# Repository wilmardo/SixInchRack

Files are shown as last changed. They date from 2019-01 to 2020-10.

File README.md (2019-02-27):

# SixInchRack

This is a project for 6" cabinets and rack enclusures.

For pictures have a look here:
 - http://www.thingiverse.com/thing:1957436
 - http://www.thingiverse.com/thing:1936196
 - http://www.thingiverse.com/thing:2084736

The project is a scaled down version of the familiar 19" rack standard, with the following size:
 - 1U is 14mm
 - The front plate is 155mm wide
 - The inside distance between the two vertical profiles is 115mm
 - The ears protrude 20mm

It is designed for the 20x20 extruded aluminium profile, but a profile can also be printed.

Screws:
 - M4x6 for the nutless trap
 - M6x16 for the top and bottom
 - M3x12 for the cabinet

##I want to print a simple blank six inch cabinet
Go Thingiverse and locate this build: http://www.thingiverse.com/thing:1957436
In the customizer you specify how many units you need in height, and depth in mm you need.
Alternatively, fetch these files from the repository:...

##I want to print a simple six inch rack enclosure for cabinets
Go Thingiverse and locate this build: http://www.thingiverse.com/thing:1957436
In the customizer you specify which parts you need.
Alternatively, fetch these files from the repository:...

##I want to print a 6" cabinet for a specific component
Either go to thingiverse where you can find the stl's and pictures, or download the stl's form this repository. Currently the following components are supported by the community:

- http://www.thingiverse.com/thing:2084736 Raspberry Pi 3 Model B
- http://www.thingiverse.com/thing:1905998 Raspberry Pi B
- http://www.thingiverse.com/thing:2151578 Beaglebone Black
- http://www.thingiverse.com/thing:2123108 DPS5005 power supply
- http://www.thingiverse.com/thing:2105698 Beaglebone Black

##I want to make a new cabinet for my favourite module
Start by inspecting this file for inspiration _RackCabinets/RaspberryPiModelB/usb_back.scad_, and take a look at the how to section below.

1. Create a new file that includes _sixinch_library.scad_
2. Customize all the parts needed for your cabinet
3. Create a new folder with you project, and anything else needed like print descriptions
4. If you like, create a Thingiverse build with pictures and your stl, and add a link in this file

##Quick How To##
A cabinet consist of five parts:
- Front plate
- Back plate
- Cabinet
- Lid
- Handles

In a new file, include _sixinch_library.scad_. For each of the parts, there is module in the library where you can specify the most commonly used features like round and square holes, and pegs for supporting PCB's etc. The following examples are for Raspberry Pi 3 cabinet. <br>
The deafult modules obviously does not support everything you need, but should give you a good start for further customization. Feel free to add functionality to the library.

###Front Plate###
```java
square_hole        = [];
round_hole         = [[65 ,7.5, 3.1],[69.5 ,7.5, 3.1]];
round_peg          = [];
screw_side_front   = [];
screw_top          = [36];
screw_bottom_front = [36];
units              = 2;
frontplate(units,square_hole,round_hole,round_peg,screw_side_front,screw_top,screw_bottom_front);
```

###Handle###
```java
units              = 2;
lay_flat_for_print = true;
handle(units,lay_flat_for_print);
```

###Cabinet###
```java
w=88;
h=70;
screw_bottom_front = [36];
screw_side_front   = [];
round_peg          = [[w,h,6,2.8,4],
                     [w-49,h,6,2.8,4],
                     [w-49,h-58,6,2.8,4],
                     [w,h-58,6,2.8,4]];
depth              = 98;
units              = 2;
cabinet(depth,units,screw_bottom_front,round_peg,screw_side_front);
```

###Lid###
```java
depth = 98;
units = 2;
screw_front = [36];//mm
screw_back  = [36];//mm
lid(98,2,screw_front,screw_back);
```

###Back plate
```java
square_hole  = [[37 ,3, 17, 15] , [57 ,4, 15, 16] , [75,4,15,16] ];
round_hole   = [[6,5,6],[6,1,6], [24,3.5,3.5],[24,1.2,3.5]  ,[30,3.5,3.5],[30,1.2,3.5]];
screw_top    = [36];//mm
screw_bottom = [36];//mm
screw_side   = [];
depth        = 98;
units        = 2;
back_plate(units,depth,screw_top,screw_bottom,screw_side,square_hole,round_hole);
```

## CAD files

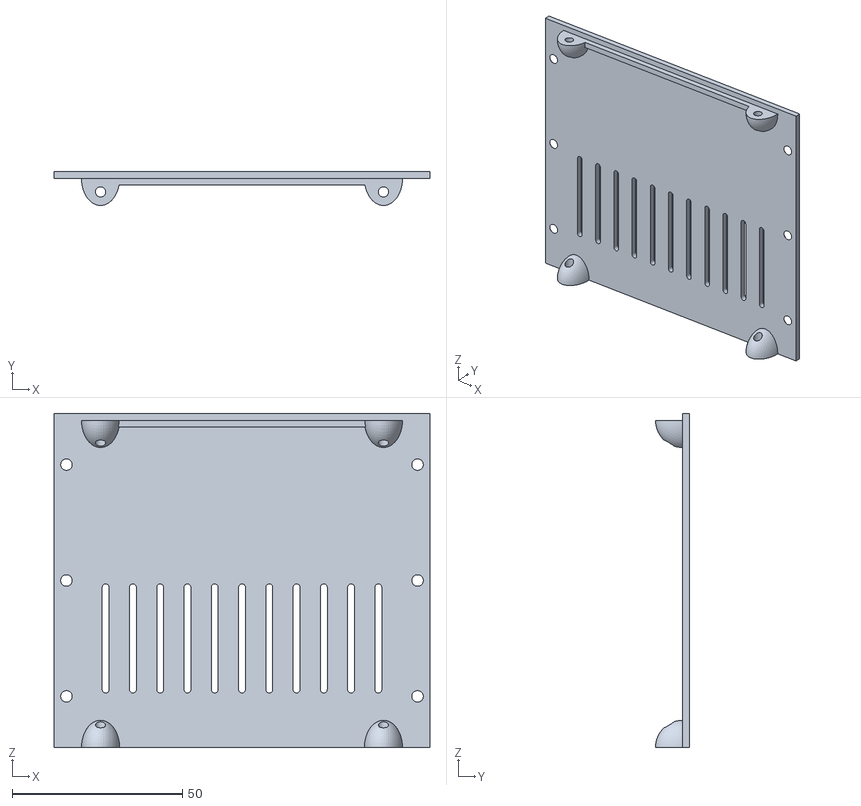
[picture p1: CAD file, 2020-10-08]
RackCabinets/Rock64/lid.stl
110.3 x 9.98 x 98.0

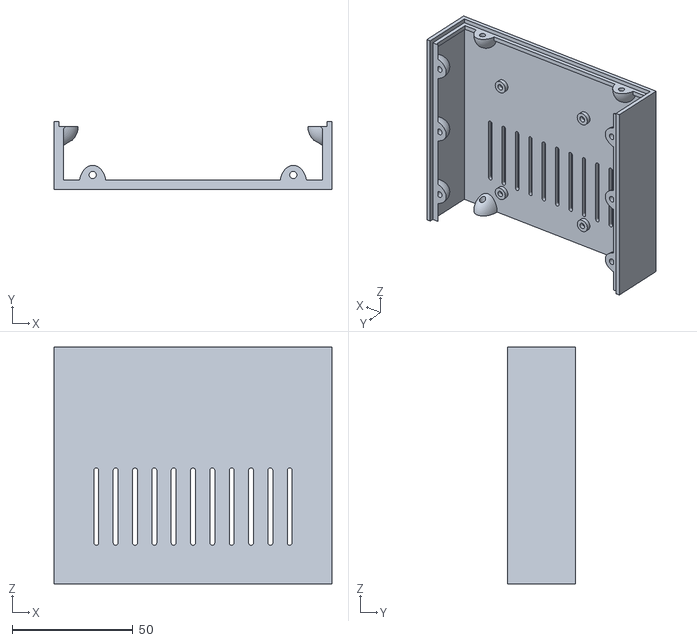
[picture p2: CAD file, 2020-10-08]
RackCabinets/Rock64/cabinet.stl
115.0 x 28.1 x 98.0

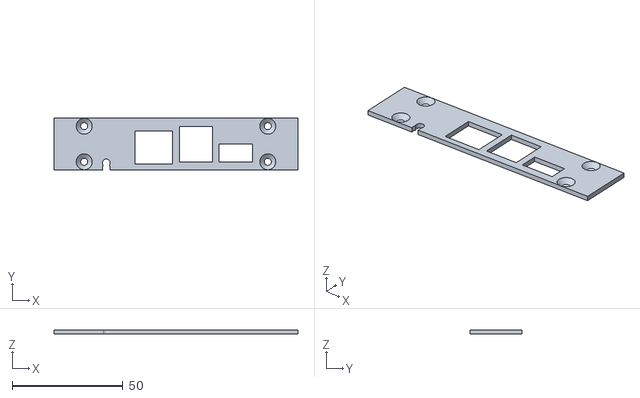
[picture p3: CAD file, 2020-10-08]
RackCabinets/Rock64/rear.stl
110.3 x 23.4 x 2.00

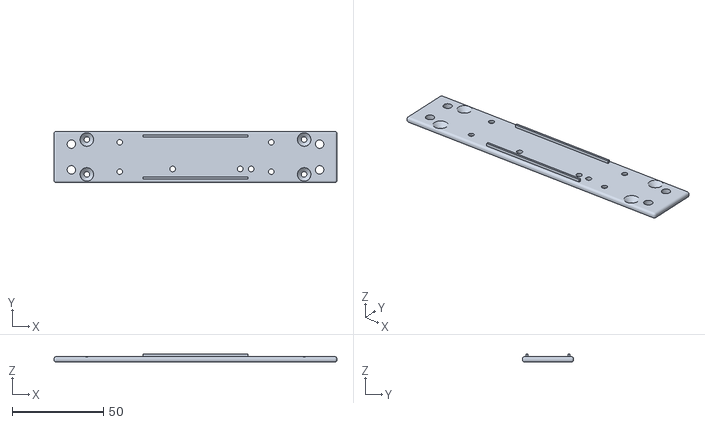
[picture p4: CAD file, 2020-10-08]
RackCabinets/Rock64/front.stl
155.0 x 28.1 x 4.50

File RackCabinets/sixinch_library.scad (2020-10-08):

$fn = 50*1;

//Constants, do not change !
sixinch   = 155*1;       // cm = 6"
width     = 155-20-20;   // 11.5cm between rails
unit      = (44.5/19)*6; // 1U
gauge     = 3*1;
gauge_box = 2*1;

//Cabinet screws in mm. They can be changed a little
screw_head        = 7.4;
screw_head_height = 2.2;
screw_dia         = 3;
screw_hole        = 2.6;
screw_length      = 15;
nut_4mm           = 8.1;
slip              = 0.35;

module chimney() {
    for(i=[0:8:80]){
        echo(i);
        translate([20 + (width-80)/2  +i,-1,20]){
            minkowski(){
                cube([0.01,200,30]);
                sphere(d=2); // TODO: lookup why h=1 was passed
            }
        }
    }
}

module back_plate(u,dp,screw_top,screw_bottom,screw_side,square_hole,round_hole){
     difference(){
        union(){
            translate([20+gauge_box+slip,gauge_box+slip,gauge+dp-gauge_box]){
                cube([width-2*gauge_box-2*slip, u*unit-2*gauge_box-2*slip, gauge_box]);
            }
        }

     //Square holes
        for(i=[0:len(square_hole)-1]){
            x = square_hole[i][0];
            y = square_hole[i][1];
            w = square_hole[i][2];
            h = square_hole[i][3];
            translate([x+20+gauge_box,y+gauge_box,dp-1]){cube([w,h,gauge+2]);}
        }

        //Round holes
        if(len(round_hole)>0){
            for(i=[0:len(round_hole)-1]){
                x = round_hole[i][0];
                y = round_hole[i][1];
                dia = round_hole[i][2];
                translate([20+gauge_box+x,gauge_box+y,dp-4]){  cylinder(d=dia,h=10); }
            }
        }


        //Screw holes
        if(len(screw_top)>0){
            for(i=[0:len(screw_top)-1]){
                p = screw_top[i];
                translate([p,unit*u-gauge_box-4,gauge+dp+0.1]){rotate([0,180,0]){screw();}}
                translate([sixinch-p,unit*u-gauge_box-4,gauge+dp+0.1]){rotate([0,180,0]){screw();}}
            }
        }
        if(len(screw_bottom)>0){
            for(i=[0:len(screw_bottom)-1]){
                p = screw_bottom[i];
                translate([p,gauge_box+4     ,gauge+dp+0.1]){rotate([0,180,0]){screw();}}
                translate([sixinch-p,    gauge_box+4    ,gauge+dp+0.1]){rotate([0,180,0]){screw();}}
            }
        }

        if(len(screw_side)>0){
            for(i=[0:len(screw_side)-1]){
                p = screw_side[i];
                translate([sixinch-20-6,    unit*p    ,gauge+dp+0.1]){rotate([0,180,0]){screw();}}
                translate([20+6,    unit*p    ,gauge+dp+0.1]){rotate([0,180,0]){screw();}}
            }
        }
    }
}

module peg(x,y,od,id,he){
    translate([x,y,0]){
        rotate([-90,0,0]){
            difference(){
                cylinder(r=od/2,h=he);
                translate([0,0,-0.5]){cylinder(r=id/2,h=he+1);}
            }
        }
    }
}

module screwtrap(){
    difference(){
        translate([0,0,5]){
            intersection(){
                scale([1,1,0.7]){
                    sphere(r=8);
                }
                translate([0,-0.001,-10]){  cube([20,20,20]);}
            }
        }
        translate([2,4,5]){
            rotate([90,90,90]){
               translate([0,0,-10]){ cylinder(r=screw_dia/2,h=20,$fn=100);}
            }
        }
    }
}

module nuttrap(){
    difference(){
        linear_extrude(10){
            polygon(points=[[0,0],[8,0],[2,8],[0,8]]);
        }
        translate([2,4,5]){
            rotate([90,90,90]){
                cylinder(r=nut_4mm/2,h=20,$fn=6);
            }
        }
        translate([2,4,5]){
            rotate([90,90,90]){
               translate([0,0,-10]){ cylinder(r=screw_dia/2,h=20,$fn=100);}
            }
        }
    }
}

module cabinet (dp,u,screw_bottom_front,round_peg,screw_side_front){
    difference(){
        box(dp,u,screw_bottom_front,round_peg,screw_side_front);

               translate([20,unit/2+3,sixinch-40]){ cylinder(d=gauge_box,h=41);}
               translate([20,unit/2+0,sixinch-40]){ cylinder(d=gauge_box,h=41);}
               translate([20,unit/2-3,sixinch-40]){ cylinder(d=gauge_box,h=41);}

               translate([20+width,unit/2+3,sixinch-40]){ cylinder(d=gauge_box,h=41);}
               translate([20+width,unit/2+0,sixinch-40]){ cylinder(d=gauge_box,h=41);}
               translate([20+width,unit/2-3,sixinch-40]){ cylinder(d=gauge_box,h=41);}


        }

    }

module box(dp,u,screw_bottom_front,round_peg,screw_side_front){
    difference(){
        translate([20,0,gauge]){
            difference(){
                cube([115,u*unit,dp]);
                translate([gauge_box,gauge_box,-1]){ cube([115-gauge_box*2,u*unit,dp+2]);}
            }
        }
        //CHIMNEY
        chimney();
    }

    //Screw mounts on the bottom plate
    for(i=[0:len(screw_bottom_front)-1]){
        p = screw_bottom_front[i];
        translate([p+5,gauge_box,gauge]){rotate([0,-90,0]){screwtrap();}}
        translate([sixinch-p+5,gauge_box,gauge]){rotate([0,-90,0]){screwtrap();}}
        translate([p-5,gauge_box,gauge+dp-gauge_box]){rotate([0,90,0]){screwtrap();}}
        translate([sixinch-p-5,gauge_box,gauge+dp-gauge_box]){rotate([0,90,0]){screwtrap();}}
   }

   //Screw mounts on the side of cabinet
   if(len(screw_side_front)>0){
        for(i=[0:len(screw_side_front)-1]){
            p = screw_side_front[i]*unit;
                translate([20+gauge_box,p-5,gauge]){rotate([0,-90,-90]){screwtrap();}}
                translate([sixinch-20-gauge_box,p+5,gauge]){rotate([0,-90,90]){screwtrap();}}
                translate([20+gauge_box,p+5,gauge+dp-gauge_box]){rotate([0,90,-90]){screwtrap();}}
                translate([sixinch-20-gauge_box,p-5,gauge+dp-gauge_box]){rotate([0,90,90]){screwtrap();}}
        }
    }

    //Screw mounts for lid. Two on each side, three if dp>90
    translate([20+gauge_box,unit*u-gauge_box,gauge+10]){rotate([0,0,-90]){screwtrap();}}
    translate([20+gauge_box,unit*u-gauge_box,gauge+dp-10-10]){rotate([0,0,-90]){screwtrap();}}
    translate([sixinch-20-gauge_box,unit*u-gauge_box,gauge+10+10]){rotate([180,0,-90]){screwtrap();}}
    translate([sixinch-20-gauge_box,unit*u-gauge_box,gauge+dp-10-10+10]){rotate([180,0,-90]){screwtrap();}}
    if(dp>90){
        translate([sixinch-20-gauge_box,unit*u-gauge_box,gauge+dp/2-5+10]){rotate([180,0,-90]){screwtrap();}}
        translate([20+gauge_box,unit*u-gauge_box,gauge+dp/2-5]){rotate([0,0,-90]){screwtrap();}}
    }

    //Lid rest bar
    translate([20+gauge_box,unit*u-3-gauge_box,gauge]){
        linear_extrude(dp-gauge_box){polygon (points=[[0,0],[3,3],[0,3]]);}
    }
    translate([sixinch-20-gauge_box,unit*u-3-gauge_box,gauge]){
        linear_extrude(dp-gauge_box){polygon (points=[[0,0],[-3,3],[0,3]]);}
    }

    // Back/front rest bar
    translate([0,0,dp+gauge-2-gauge_box]){
        difference(){
            translate([20,0,0]){  cube([width,unit*u-gauge_box,2]);  }
            translate([20+gauge_box+2,gauge_box+2,-1]){  cube([width-2*gauge_box-4,unit*u,4]);  }
        }
    }

    //PEGS Relative to inside corner
    translate([20+gauge_box,0,gauge]){
        if(len(round_peg)>0){
            for(i=[0:len(round_peg)-1]){
                x = round_peg[i][0];
                y = round_peg[i][1];
                od = round_peg[i][2];
                id = round_peg[i][3];
                he = round_peg[i][4];
                translate([x,0,y]){peg(0,0,od,id,he); }
             }
        }
    }
}

module lid(dp,u,screw_front,screw_back){
    difference(){
        union(){
            if(len(screw_front)>0){
                for(i=[0:len(screw_front)-1]){
                    p = screw_front[i];
                    translate([p-5,unit*u-gauge_box,gauge]){rotate([0,-90,180]){screwtrap();}}
                    translate([sixinch-p-5,unit*u-gauge_box,gauge]){rotate([0,-90,180]){screwtrap();}}
                }
            }
            if(len(screw_back)>0){
                for(i=[0:len(screw_back)-1]){
                    p = screw_back[i];
                    translate([p+5,unit*u-gauge_box,gauge+dp-gauge_box]){rotate([0,90,180]){screwtrap();}}
                    translate([sixinch-p+5,unit*u-gauge_box,gauge+dp-gauge_box]){rotate([0,90,180]){screwtrap();}}
                }
            }

            //lid
            translate([20+gauge_box+slip,u*unit-gauge_box,gauge]){
                cube([115-gauge_box*2-slip*2,gauge_box,dp]);
            }
            //back rest
            translate([sixinch/2-40,u*unit-gauge_box-2,gauge+dp-2-gauge_box]){
                cube([80,2,2]);
            }
        }
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

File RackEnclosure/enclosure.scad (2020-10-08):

// This file contains all the parts for a rack enclosure
// It has the format required for a customizable project on Thingiverse
// Note: Calculated variables does not show up in the customizer, hence the *1;

$fn = 50*1;

part = "h"; // [a:Extrusion no holes,b:Extrusion front holes,c:Extrusion front and side holes,d:End open,e:End grid,f:End chimney,g:End closed,h:Nut-less Trap,i:Panel,j:Panel with handle,k:Handle]

Units = 12;

//Hole size for 4mm screws or freedom unit equivalent
Four_mm_screw = 3.5;

//Hole size for 5mm screws or freedom unit equivalent
Five_mm_screw = 4.8;

//Constants, do not change !
sixinch   = 155*1;       // cm = 6"
width     = 155-20-20;   // 11.5cm between rails
unit      = (44.5/19)*6; // 1U = 14.05cm
gauge     = 3*1;
gauge_box = 2*1;
slip      = 0.35*1;      // extra slip between parts

go();

module go(){
    if (part=="a"){
        extrusion(Units,true,false,false);
    }else if (part=="b"){
        extrusion(Units,true,true,false);
    }else if (part=="c"){
        extrusion(Units,true,true,true);
    }else if (part=="d"){
        rack_end(0);
    }else if (part=="e"){
        rack_end(1);
    }else if (part=="f"){
        rack_end(2);
    }else if (part=="g"){
        rack_end(3);
    }else if (part=="h"){
        trap(Units);
    }else if (part=="i"){
        sidepanel(Units,false);
    }else if (part=="j"){
        sidepanel(Units,true);
    }else if (part=="k"){
        tophandle();
    translate([0,30,0]){tophandle();}
    }
}

module chimney() {
    for(i=[0:8:80]){
        echo(i);
        translate([20 + (width-80)/2  +i,-1,20]){
            minkowski(){
                cube([0.01,50,30]);
                sphere(d=2,h=1);
            }
        }
    }
}

// Nut-less Trap
module trap(u){
    difference(){
        union(){
            translate([-2.4,0,4]){
                cube([4.8,unit*u,1.5]);
            }
            translate([-2.4,unit*u,0]){
                rotate([90,0,0]){
                    linear_extrude(unit*u){
                        polygon(points=[[0,0],[4.8,0],[7,4],[-2.2,4]]);
                    }
                }
            }
        }
        for(i=[1:u]){
            translate([0,unit*i-unit/2,-1]){
                cylinder(d=Four_mm_screw,h=10);
            }
        }
    }
}

//0: open
//1: grid
//2: chimney
//3: closed
module rack_end(type){
    width = sixinch+1;
    difference(){
        union(){
            translate([1.25,1.25,1.25]){
                minkowski(){
                    w = width-2.5;
                    cube([w, w, gauge-2.5]);
                    sphere(r=1.25);
                }
            }
        }
        if(type==0 || type==1){
            translate([20,20,-1]){ cube([width-40,width-40,gauge+2]);}
        }

        translate([10,10,-0.1])                { cylinder(d=5,h=10); cylinder(d1=10,d2=6,h=3.5);}
        translate([width-10,10,-0.1])        { cylinder(d=5,h=10); cylinder(d1=10,d2=6,h=3.5);}
        translate([10,width-10,-0.1])        { cylinder(d=5,h=10); cylinder(d1=10,d2=6,h=3.5);}
        translate([width-10,width-10,-0.1]){ cylinder(d=5,h=10); cylinder(d1=10,d2=6,h=3.5);}

        rotate([-90,0,0]){
            if(type==2){
                translate([0,-5,0]){chimney();}
                translate([0,-5,(width-29)/2]){chimney();}
                translate([0,-5,width-29]){chimney();}
            }
        }
    }
    if(type==1){
        intersection(){
            union(){
                sz=8;
                grid = 15;
                for(i=[-grid*8:12:grid*8]){
                    translate([sz/2+i+70,sz/2+78,gauge/2]){
                        rotate([0,0,45]){
                        cube([2,width*1.5,gauge],center=true);
                        }
                    }
                    translate([sz/2+i+70,sz/2+82,gauge/2]){
                        rotate([0,0,-45]){
                            cube([2,width*1.5,gauge],center=true);
                        }
                    }
                }
            }
            translate([15,15,-1]){cube([125,125,10]);}
        }
    }
}

module tophandle(){
    rotate([0,180,0]){
        difference(){
            union(){
                rotate([0,45,0]){
                    extrusion(4,false,false,false);
                }
                translate([sixinch,20,0]){
                    rotate([0,45,180]){
                        extrusion(4,false,false,false);
                    }
                }
            }
            wedge();
            translate([90,90,10]){
                cube([200,200,20],center=true);
            }
            translate([10,10,0]){handlescrew();}
            translate([sixinch-10,10,0]){handlescrew();}
        }
        intersection(){
            translate([0,0,-27.4]){
                extrusion(11,false,false,false);
            }
            wedge();
        }
    }
}

module handlescrew(){
    translate([0,0,-39]){cylinder(d=5,h=40); }
    translate([0,0,-4]){cylinder(d1=10,d2=6,h=3.5);}
    translate([0,0,-34]){cylinder(d=10,h=30);}
}

module wedge(){
    translate([sixinch/2,-10,15]){
        rotate([0,45+45/2,0]){
            cube([80,80,30]);
        }
        translate([0,80,0]){
            rotate([0,45+45/2,180]){
                cube([80,80,30]);
            }
        }
        translate([-20,0,-100]){
            cube([40,80,100]);
        }
    }
}

module extrusion(u,center,front,side){
    len=unit*u;
    difference(){
        translate([0,2,2]){
            minkowski(){
                cube([len,16,16]);
                sphere(d=4);
            }
        }
        translate([-5,10,1.99]){
            rotate([0,90,0]){linear_extrude(len+10){polygon(points=[[0,-2.5],[2,-4],[2,4],[0,2.5]]);}}
        }
        translate([-5,10,18.01]){
            rotate([0,-90,180]){linear_extrude(len+10){polygon(points=[[0,-2.5],[2,-4],[2,4],[0,2.5]]);}}
        }
        translate([-5,18.01,10]){
            rotate([90,0,90]){linear_extrude(len+10){polygon(points=[[0,-2.5],[2,-4],[2,4],[0,2.5]]);}}
        }
        translate([-5,1.99,10]){
            rotate([-90,0,-90]){linear_extrude(len+10){polygon(points=[[0,-2.5],[2,-4],[2,4],[0,2.5]]);}}
        }
        if(center){
            translate([-5,10,10]){
                rotate([0,90,0]){
                    cylinder(d=4.6,h=len+10);
                }
            }
        }
        //holes
        if(front){
            for(i=[0:30]){
                translate([unit/2+i*unit,10,-5]){ cylinder(d=3.8,h=30);}
            }
        }
        if(side){
            for(i=[0:30]){
                translate([unit/2+i*unit,25,10]){ rotate([90,0,0]){cylinder(d=3.8,h=30);}}
            }
        }
        //length cutoff
        translate([-2,0,0]){cube([4,60,60],center=true);}
        translate([len+2,0,0]){cube([4,60,60],center=true);}
    }
}

module screw(){
    cylinder(r1=screw_head/2, r2=screw_dia/2, h=screw_head_height);
    cylinder(r=screw_dia/2, h=40);
    translate([0,0,-0.99]){cylinder(r=screw_head/2, h=1);}
}

module insideprofile(l){
    difference(){
        union(){
            translate([7.6,10,0]){cube([4.8,10,l]);}
            translate([0,7.6,0]){cube([20,4.8,l]);}

            translate([6.5,10-2.1,0]){cube([7   ,10,l]);}
            translate([2.1,6.5,0]){cube([15.8,7   ,l]);}
        }
        translate([4,4,-1]){
            cube([12,12,l+2]);
        }
    }
    translate([20,20,0]){
        rotate([0,-90,0]){
            linear_extrude(20){
                polygon (points=[[0,0],[l,0],[0,l]]);
            }
        }
    }
}

module sidepanel(u,handle){
    difference(){
        baseplate(u);
        if(handle){
              translate([(sixinch-80)/2,         9,-4]) { cube([80,20,10]);}
              translate([(sixinch-80)/2,        19,-4]) { cylinder(d=20,h=10);}
              translate([sixinch-(sixinch-80)/2,19,-4]) { cylinder(d=20,h=10);}
        }
    }
}

module baseplate(u){
    difference(){
        union(){
            translate([1.25,1.25,1.25]){
                minkowski(){
                    cube([sixinch-2.5,unit*u-2.5,gauge-2.5]);
                    sphere(r=1.25);
                }
            }
        }
        //Rack mount holes
        translate([10-0.5,unit/2,-gauge/2])                 {cylinder(r=2.3,gauge*2);}
        translate([sixinch-10+0.5,unit/2,-gauge/2])         {cylinder(r=2.3,gauge*2);}
        translate([10-0.5,u*unit-(unit/2),-gauge/2])        {cylinder(r=2.3,gauge*2);}
        translate([sixinch-10+0.5,u*unit-(unit/2),-gauge/2]){cylinder(r=2.3,gauge*2);}
        if(u>=5){
            translate([10-0.5,(u*unit)/2,-gauge/2])         {cylinder(r=2.3,gauge*2);}
            translate([sixinch-10+0.5,(u*unit)/2,-gauge/2]) {cylinder(r=2.3,gauge*2);}
        }
    }
}

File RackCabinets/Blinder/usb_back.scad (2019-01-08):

include<../sixinch_library.scad>


  ///////////////////////////////
 // Blinder                    //
///////////////////////////////

print_blinder_sml = true;

if(print_blinder_sml){ // Blinder //
    units              = 2; 
    blinder(units);
}

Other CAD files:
RackCabinets/RaspberryPi3ModelB/usb_back.scad
RackCabinets/RaspberryPi4/usb_back.scad
RackCabinets/RaspberryPiModelB/usb_back.scad
RackCabinets/Rock64/usb_back.scad

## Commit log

2019-01-08 Adds blinder, rock64 needs rebase of code
    [blinder.stl, sixinch_library.scad, usb_back.scad]
2019-02-27 Updates README, adds more fixes
    [blinder.stl, enclosure.scad, sixinch_library.scad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]
2020-10-01 chore: remove trailing lines
    [usb_back.scad]
2020-10-08 chore: remove trailing lines and spaces
    [cabinet.stl, front.stl, lid.stl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]
2020-10-08 chore: markup
    [enclosure.scad, sixinch_library.scad, usb_back.scad]
2020-10-08 chore: adds proper spacing
    [usb_back.scad]
2020-10-08 feat: adds Raspberry Pi4
    [usb_back.scad]
2020-10-08 chore: quick formatting fixes
    [sixinch_library.scad]
